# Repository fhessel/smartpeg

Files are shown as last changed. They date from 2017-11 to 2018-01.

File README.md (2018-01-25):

# smartpeg
Project "Smarte Wäscheklammer" for Ambient Intelligence at TU Darmstadt, winter term 2017/18

## About the project
This repository contains hardware definitions and software to build a prototype of a _smart peg_ that you can attach to your
drying laundry. It will estimate the remaining time until the laundry is completely dry and notifcy you on your Android phone.

The project consists of the following components:

- The hardware, an actual peg, an ESP8266 microcontroller board, humidity and temperature sensors and a battery. Descriptions on
how to build the hardware are available in the `hardware/schematics` folder.
- The microcontroller software, written in C/C++, can be found at `hardware/code`, more details on how to build it are provided
by the README file in the `hardware` folder.
- The server component, written as Java Web Application (we used Tomcat for testing), can be found in the `api` directory,
together with the database and API description files
- The machine learning scripts are written in Python 3 and use TensorFlow, they are located in the `server` directory
- The Android app, written in Java, is located in the `app` folder.

## What it looks like

The final hardware prototype looked like that. The PCB as well as the battery have roughly the length of the peg, so they can be glued together easily:

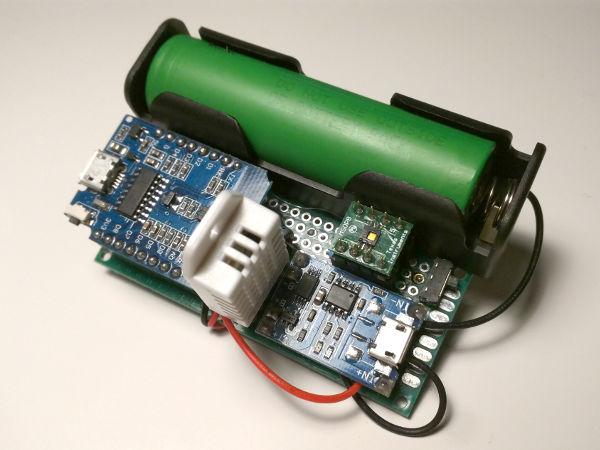
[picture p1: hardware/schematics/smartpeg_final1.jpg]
Front view of the final hardware prototype

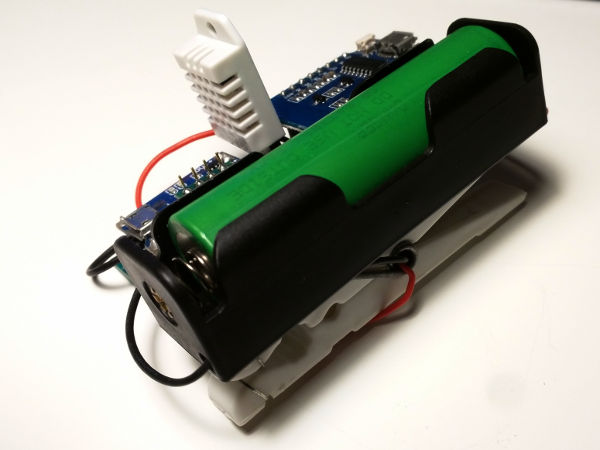
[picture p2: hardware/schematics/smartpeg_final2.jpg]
Rear view of the final hardware prototype


The following image shows a screenshot of one drying process together with the prediction of the neural network:

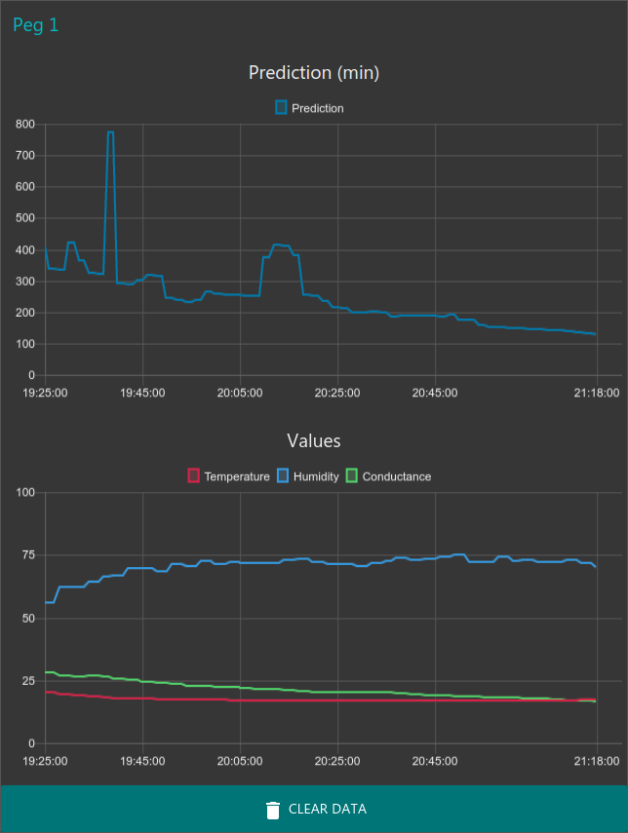
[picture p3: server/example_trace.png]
Prediction and measurement values


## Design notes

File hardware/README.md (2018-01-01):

# Hardware

This folder contains a description of the hardware (schematics) as well as the source code
for the ESP8266.

## Schematics

The subfolder contains the circuit design and schematics. The files can be edited with
[Fritzing](http://fritzing.org/home/).

### Parts list

The project currently makes use of:

- An ESP8266 development board, compatible to NodeMCU
  - XSource ESP8266 D1 mini ([Amazon Link](https://www.amazon.de/gp/product/B01ELFAF1S/))
  - Note: It has a slightly different pin layout as the more common Wemos D1 mini!
- A DHT22 temperature and humidity sensor
  - DHT11 should also work, if configured in the code
- A TI HDC1080 temperature and humidity sensor
  - Soldered on a 2x4 pin 0.1" breakout board for better handling
- A 20 mA blue LED
- Some resistors:
  - One 68 ohm resistor (for the LED)
  - One 1 mega ohm resistor (for measuring conductance of the clothes)
  - Two 4.7 kilo ohm resistors (pull-up for communication lines of I²C)
- A 470µF capacitor
- A switch
- A 1N4007 diode
- A peg that has wires on both of the clamp
- An 18650 LiPo battery (capacity should be irrelevant, but the one used had 2500mAh)
  - Charging controller including TP4056 (charging) and DW01x (discharge protection)
  - Holder for the battery

The 1N4007 diode is used to introduce a fixed voltage drop, because the 4.2V present while micro USB for
charging is connected would harm the ESP8266.

### Resources

- [Guide on calculating I²C pullup resistors](http://www.ti.com/lit/an/slva689/slva689.pdf) by Texas Instrucments
- [Data Sheet for HDC1080](http://www.ti.com/lit/ds/symlink/hdc1080.pdf) temperature and humidity sensor
- [Data Sheet for DHT22](https://www.sparkfun.com/datasheets/Sensors/Temperature/DHT22.pdf) temperature and humidity sensor

### Circuit Design

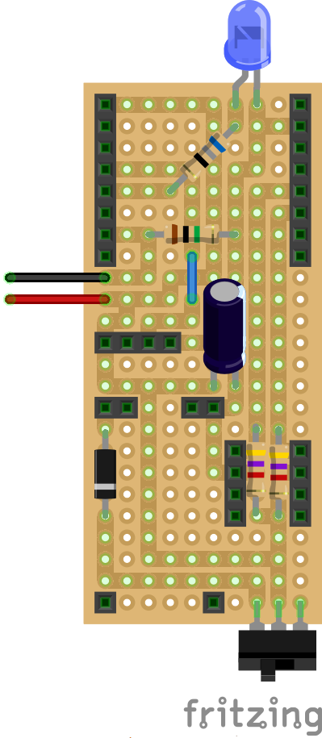
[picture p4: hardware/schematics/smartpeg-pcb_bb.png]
Circuit on PCB


The PCB layout uses female headers for most components, including sensors, the ESP8266 board and a PCB that contains the components
for control of charging and discharging. It has the dimensions of 10 by 24 and uses the common 0.1 inch distance between holes.

Both of the top-most size 8 headers are used to connect the ESP8266 board, with the micro USB port facing to the upper side of the image.
This means, the (unused) 5V pin is on the top-right corner.

The single size 4 header on the left is used to connect the DHT22, with the Vcc pin at the border of the PCB.

On the bottom right, there are two size four headers to connect the HDC1080, and on the bottom left, the charging controller is placed on the
remaining headers.

The following photo shows the assembled PCB, the battery and the peg:

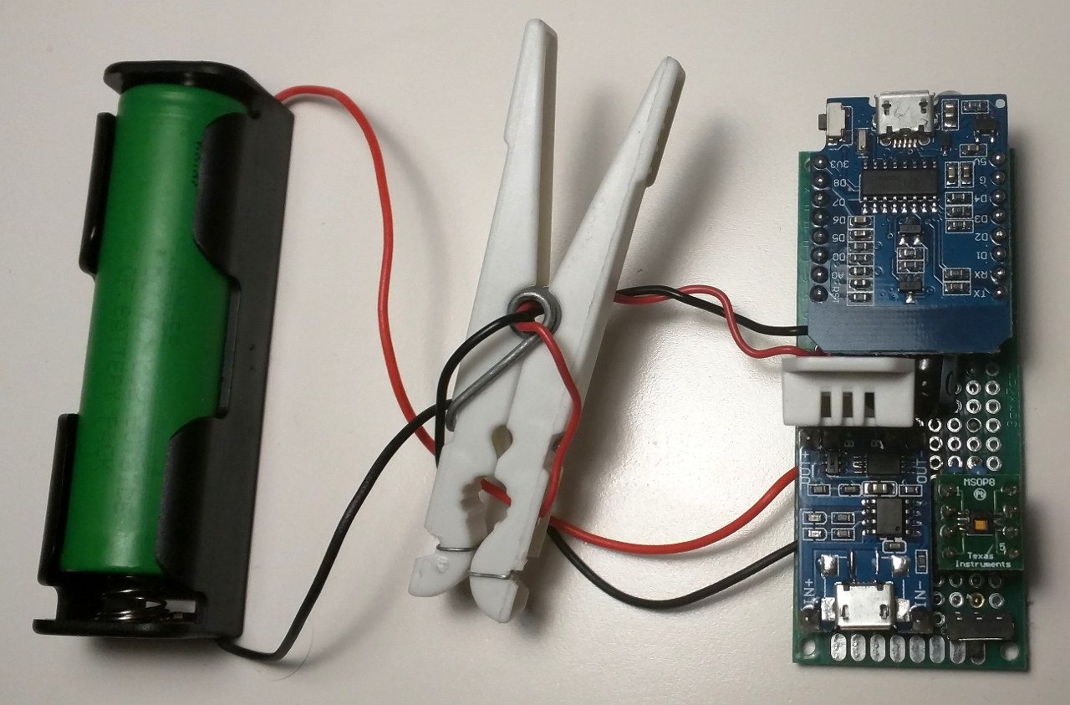
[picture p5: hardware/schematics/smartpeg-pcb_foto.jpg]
Photo of PCB


**Note:** Only one sensor is required for the circuit, if you decide to assemble it with only one sensor, the other one can be disabled in the code.

## Code

The code subfolder contains the project that generates the program running on the ESP8266
microcontroller.

### Setup

While the ESP8266 is Arduino-compatible, for bigger projects a full IDE is easier to use.
For that reason, the project is developed using the Eclipse-based [Sloeber IDE](http://eclipse.baeyens.it/).

The code folder is an Eclipse project folder that can be imported into a normal workspace.

To setup the development environment:

- Download [Sloeber](http://eclipse.baeyens.it/)
- Get the [ESP8266 Arduino Core](https://github.com/esp8266/Arduino) and follow the instructions to install it.
- Checkout the project into a new workspace
- Copy all foo.example.h files in the /config folder to get an individual configuration (instructions included in the files)
- Compile the project and upload it to the board

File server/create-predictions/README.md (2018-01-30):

# createPredictions.jar

Some lines of Java code to re-generate historical predictions. Needs mariadb connector and Apache commons-lang3 as jar in the classpath and should be exported as createPredictions.jar. Remember configuring the values in the DatabaseConnector class.

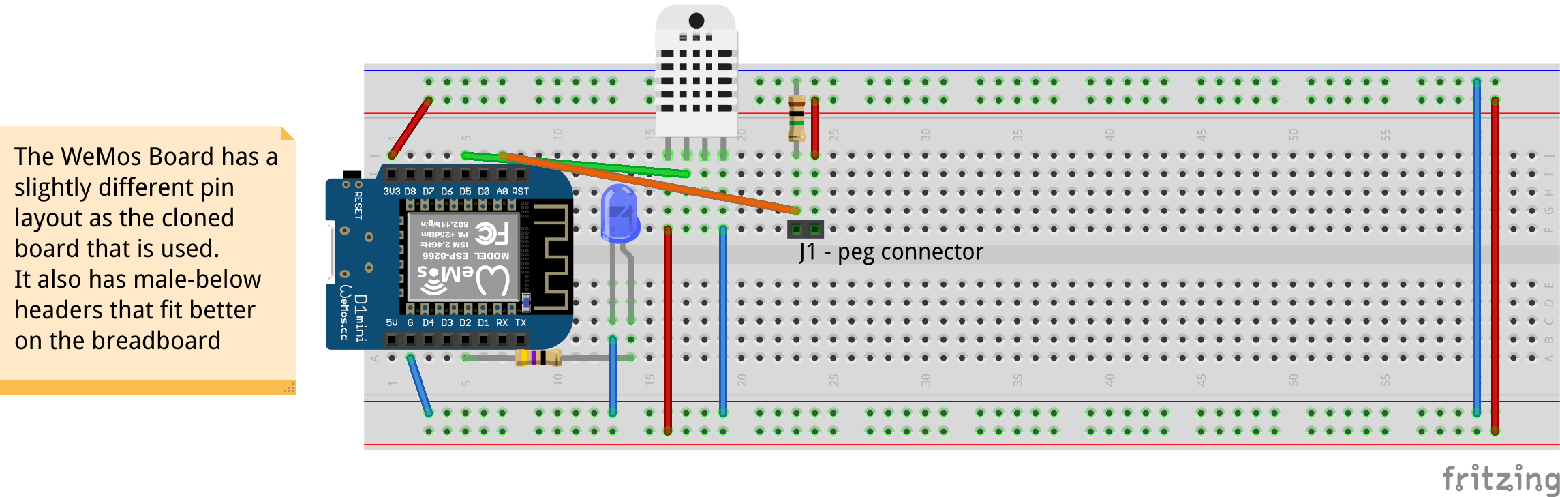
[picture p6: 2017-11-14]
hardware/schematics/smartpeg_bb.png

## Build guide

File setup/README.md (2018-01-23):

# Setup instructions

This guide will help you setting up the project including the server. For development purposes, we used a Raspberry Pi (Version 3) as server. Other distributions or even OSs should work, but the further you get away from Debian-like systems, the more things will have to be adapted.

## Setting up the server

The server is a Java web application, so it needs a Java server that is at least capable of running the Web Profile. In our case, Tomcat 8 was quite useful. It also requires a JDK:

```
apt-get install tomcat8 openjdk-8-jdk
```

Besides that, we need a database to store measurements, known pegs etc. We used MySQL and MariaDB for this:

```
apt-get install mariadb-server mariadb-client
```

The server needs to have the **right JDBC-Connector in the classpath**, so for example download [mariadb-java-client-2.2.0.jar](https://downloads.mariadb.org/connector-java/2.2.0/) and put it into `/var/lib/tomcat8/lib/`.

Create a `smartpeg` database user with a secure password and his own database `smartpeg`. The setup script for the database as `api/databaseDef.sql` in the repository.

The newly-created database then has to be configured in the server. To do so, edit `/var/lib/tomcat8/conf/context.xml` and add the following lines:

```
<Resource name="jdbc/smartpeg" auth="Container"
	type="javax.sql.DataSource"
	description="Connection to MariaDB"
	username="smartpeg"
	password="the-secure-password-you-created-before"
	driverClassName="org.mariadb.jdbc.Driver"
	url="jdbc:mariadb://localhost:3306/smartpeg"
/>
```

For the python scripts (machine learning), we need to point the server to a script location. This may be anywhere in the system (however, the server needs write access), but to use it in combination with the auto deployment feature (see below), we put it in a path on the `smartpeg` user's home directory.

This location also needs to be configured in the `context.xml`:

```
<Environment name="pythonServerBase" value="/home/smartpeg/data/smartpeg-python" type="java.lang.String"/>
```

**Note:** For the development server started within the IDE, a sample local configuration file is provided within the workspace and included in the maven build file.

**Note:** This is a very simple configuration, where the SmartPeg app will be the only app deployed in the servers root. In a multi-app setup, it's __highly__ recommended to make the above configuration entries in an app-only visible context file.

After configuring everything, restart the server: `systemctl restart tomcat8`

## Python-Scripts

The `server` folder of the repository contains python scripts for machine learning and some previously trained models. They need to be located at a place where the `tomcat8` (managing the virtual environment) user may write, as well as the `smartpeg` user (auto deployment feature, see below).

We use a directory in the home-directory of the `smartpeg` user:

```
mkdir /home/smartpeg/data
mkdir /home/smartpeg/data/smartpeg-python
chown smartpeg:tomcat8 /home/smartpeg/data/smartpeg-python
chmod u=rw,g=rws,o=r /home/smartpeg/data/smartpeg-python
```

To populate the folder, either run auto deployment or copy the content of the `server` directory of the repository into `smartpeg-python`.

Eventhough a virtual environment is created, some prequisites have to be available on the system to do so:

```
apt-get install python3 python3-virtualenv python-virtualenv libblas-dev liblaspack-dev libatlas-dev libatlas-base-dev
```

**Note:** The Java application will call a shell script (`predict.sh`). When setting up the application on Windows, this has to be changed in the Java code.

**Note:** The Python virtual environment is created on-the-fly when the first prediction should be made by the `predict.sh` shell script.

## Autodeployment

Auto deployment is a tool that updates Java and Python application everytime the `deploy-master` branch of the remote repository changes.

More details on it can be found in the autodeployment subfolder.

## Manual deployment

To deploy the application manually, run the following commands to build it (working directory: `api/rest` in the repository):

```
mvn clean
mvn install
```

Then, copy rename the created `.war`-file from the `target` directory to `ROOT.war` and drop it into `/var/lib/tomcat8/smartpeg/`

The server will update the application within some seconds.

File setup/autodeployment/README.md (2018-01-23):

# Autodeployment

This folder contains all scripts that are required to deploy changes in the repository automatically to the server.

The script ...
- Pulls from git
- Compares the hashcodes of the previous and the new latest commit, and stops if nothing has changed
- When a change has been detected, the script
  - Performs a maven clean on the Java source code directory
  - Performs a maven build on the Java source code directory
  - Deletes the local python folder
  - Copys everything from the server directory of the repository to the local python folder
  - Deploys the latest build of the Java web application to the local tomcat8 server
- Finally, depending of the outcome of the deployment process, a success or failure notice is sent to all recipients listed in `mail.addresses.notify`

**Note:** It might be a good idea NOT to run this script directly from the local copy of the repository as it might override itself during auto deployment with undefined behavior. Furthermore, the script creates temporary files in this directory that are not included from version control, which may lead to failing pulls.

**Note:** The script is configured to keep up to the **branch** `deploy-api`, so that not every change to the master automatically gets pulled by the server.

## Setup of the script

Checkout the project's repository at `~/repositories/smartpeg` in the home of your `smartpeg` user.

Copy the whole `autodeployment` folder to `~/cron/autodeploy-smartpeg-api` in the home directory of your `smartpeg` user.

Check all template-files etc. for optional adjustment (e.g. you want to change the mail address in the notification templates)

If not yet done, `apt-get install tomcat8 openjdk-8-jdk maven sendmail git` and configure sendmail properly.

Make sure, the `smartpeg` user is allowed to write to `/var/lib/tomcat8/smartpeg/` and that it is member of the group `tomcat8` to delete temporary files created while running the scripts.

To activate the script, create a cron job to call the `cron.sh` script regularly, for example, if you wish a check for updates every 10 minutes, you can use the following line:

```
#  m   h  dom   mon   dow   command
*/10   *    *     *     *   /home/smartpeg/cron/autodeploy-smartpeg-api/cron.sh > /dev/null
```

The `smartpeg` user needs to be able to (at least) read the git repository to do the pull. In practice, GitHub's _deployment keys_ feature might become handy here.

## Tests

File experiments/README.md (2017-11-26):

# Experiments

This folder contains data captured during experiments with the hardware, machine learning etc.

## Hardware traces

2017-11-11-experiment01.csv is the first trace under real conditions and has a duration of 8h, it was captured indoor on a rainy day,
with an open window. At the end of the trace, most of the clothes have been dry, the sweatshirt with the sensor attached
to it did not completely dry within the 8 hours (that's why the sensor readings do not reach 0 in the end).

2017-11-14-experiment02.csv - real conditions, indoor, not rainy, window open. The first 3 hours are not included in the trace,
in the end, the clothes have been mostly dry. Some gaps in the data are caused by the tcp wifi transmission protocol, which is
not that stable.

2017-11-20-experiment03.csv - real conditions, indoor, rainy, window open. Starts in the moment the clothes started to dry.

2017-11-25-experiment04.csv - real conditions, indoor, rainy day, from beginning. Includes readings for both sensors.

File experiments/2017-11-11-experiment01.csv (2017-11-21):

sensor | time_ms | humidity_percent | temperature_degc | dryness_raw
DHT22 | 2369853 | 51.099998 | 22.299999 | 51.710655
DHT22 | 2370629 | 51.099998 | 22.299999 | 45.259041
DHT22 | 2371130 | 51.099998 | 22.299999 | 43.206257
DHT22 | 2371631 | 51.099998 | 22.299999 | 41.935482
DHT22 | 2372132 | 50.900002 | 22.299999 | 56.989246
DHT22 | 2372908 | 50.900002 | 22.299999 | 57.575756
DHT22 | 2373409 | 50.900002 | 22.299999 | 50.439884
DHT22 | 2373910 | 50.900002 | 22.299999 | 47.311829
DHT22 | 2374411 | 50.799999 | 22.299999 | 40.762463
DHT22 | 2375187 | 50.799999 | 22.299999 | 53.372433
DHT22 | 2375688 | 50.799999 | 22.299999 | 57.575756
DHT22 | 2376189 | 50.799999 | 22.299999 | 55.816227
DHT22 | 2376690 | 50.599998 | 22.200001 | 39.687195
DHT22 | 2377466 | 50.599998 | 22.200001 | 40.273705
DHT22 | 2377967 | 50.599998 | 22.200001 | 40.566959
DHT22 | 2378468 | 50.599998 | 22.200001 | 41.055717
DHT22 | 2378969 | 50.500000 | 22.299999 | 36.265884
DHT22 | 2379745 | 50.500000 | 22.299999 | 39.980450
DHT22 | 2380246 | 50.500000 | 22.299999 | 39.589443
DHT22 | 2380747 | 50.500000 | 22.299999 | 40.175953
DHT22 | 2381248 | 50.500000 | 22.400000 | 22.482893
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

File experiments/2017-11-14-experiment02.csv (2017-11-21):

sensor | time_ms | humidity_percent | temperature_degc | dryness_raw
DHT22 | 71338 | 56.799999 | 21.799999 | 23.264908
DHT22 | 72113 | 56.799999 | 21.799999 | 22.971651
DHT22 | 72614 | 56.799999 | 21.799999 | 2.443793
DHT22 | 73115 | 56.799999 | 21.799999 | 0.000000
DHT22 | 73616 | 56.799999 | 21.799999 | 23.460411
DHT22 | 74391 | 56.799999 | 21.799999 | 22.971651
DHT22 | 74892 | 56.799999 | 21.799999 | 2.346041
DHT22 | 75393 | 56.799999 | 21.799999 | 0.000000
DHT22 | 75894 | 56.799999 | 21.799999 | 23.460411
DHT22 | 76669 | 56.799999 | 21.799999 | 23.264908
DHT22 | 77170 | 56.799999 | 21.799999 | 1.857283
DHT22 | 77671 | 56.799999 | 21.799999 | 0.000000
DHT22 | 78172 | 56.799999 | 21.799999 | 23.264908
DHT22 | 78947 | 56.799999 | 21.799999 | 22.873899
DHT22 | 79448 | 56.799999 | 21.799999 | 1.857283
DHT22 | 79949 | 56.799999 | 21.799999 | 0.000000
DHT22 | 80450 | 56.799999 | 21.799999 | 23.655914
DHT22 | 81225 | 56.799999 | 21.799999 | 22.971651
DHT22 | 81726 | 56.799999 | 21.799999 | 1.173020
DHT22 | 82227 | 56.799999 | 21.799999 | 0.000000
DHT22 | 82728 | 57.000000 | 22.000000 | 23.264908
DHT22 | 83503 | 57.000000 | 22.000000 | 22.776148
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

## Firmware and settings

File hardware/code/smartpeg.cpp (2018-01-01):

// Do not remove the include below
#include "smartpeg.h"

#ifdef USE_HDC1080
// Temperature and humidity sensor HDC1080, connected to D2 (=SDA) and D1 (=SCL) via I²C
HDC1080 sensor = HDC1080(SDA, SCL);
#endif

#ifdef USE_DHT22
DHT dht = DHT(PIN_DHT22, DHT22);
#endif

// Peg sensor (checks for conductivity of the peg)
Peg peg    = Peg(PIN_PEG);

String url = "http://smartpeg.fhessel.de/smartpeg/peg/" + String(PEG_ID) + "/readings";

//The setup function is called once at startup of the sketch
void setup()
{
	// Setup status LED
	pinMode(PIN_LED_WIFI, OUTPUT);

	setupSerialMonitor();

	// Signal initiation of setup
	for (int i = 0; i < 3; i++) {
		delay(500);
		digitalWrite(PIN_LED_WIFI, HIGH);
		delay(500);
		digitalWrite(PIN_LED_WIFI, LOW);
	}

// Configure sensors depending on the configuration in config/measurement.h
#ifdef USE_DHT22
	setupDHTSensor();
#endif
#ifdef USE_HDC1080
	setupHDCSensor();
#endif
#ifndef USE_HDC1080
#ifndef USE_DHT22
	Serial.println("ERROR: NO SENSOR CONFIGURED. PLEASE ACTIVATE EITHER \"USE_DHT22\" OR");
	Serial.println("       \"USE_HDC1080\" IN config/measurement.h!");
#endif
#endif
	setupWiFi();

	Serial.println(String("Trasmitting values to ") + url);

	// Signal finish of setup
	for (int i = 0; i < 3; i++) {
		delay(800);
		digitalWrite(PIN_LED_WIFI, HIGH);
		delay(200);
		digitalWrite(PIN_LED_WIFI, LOW);
	}
}

// The loop function is called in an endless loop
void loop()
{
	// Show the sensor is alive
	digitalWrite(PIN_LED_WIFI, HIGH);
	delay(50);
	digitalWrite(PIN_LED_WIFI, LOW);
	delay(50);

	float dryness     = peg.readDryness();

#ifdef USE_HDC1080
	float temperature = sensor.getTemperature();
	float humidity    = sensor.getHumidity();

	// Start transmitting only after the sensors are ready
	if (temperature + humidity > 0.001f) {
		// humidity, temperature, dryness
		storeMeasurement(temperature, humidity, dryness, SENSOR_TYPE_HDC1080);
	} else {
		Serial.println("HDC Sensor is not ready, not recording any values");
	}
#endif

#ifdef USE_DHT22
	float temperatureDht = dht.readTemperature();
	float humidityDht    = dht.readHumidity();

	storeMeasurement(temperatureDht, humidityDht, dryness, SENSOR_TYPE_DHT22);
#endif

#ifdef USE_HDC1080
	// Trigger next measurement (the sensor needs some time);
	sensor.triggerMeasurement();
#endif

	// The following code is the strategy to keep WiFi off for most of the time to save energy.
	// We store all measurements in an array and only transmit them if the array is nearly full
	// (nearly full to avoid dismissing values if the transmission fails)

	// Check remaining storage space (in periods, that's why we devide by PER_STEP).
	int storageSpaceLeft = (MEASUREMENT_STORAGE_SIZE - storedMeasurementsPointer) / MEASUREMENTS_PER_STEP;

	Serial.print("Measurements have been taken. ");
	Serial.print(storedMeasurementsPointer);Serial.print(" of ");Serial.print(MEASUREMENT_STORAGE_SIZE);
	Serial.print(" are used. ");Serial.print(storageSpaceLeft);Serial.println(" periods until buffer is full");

	// If less than TRANSMIT_PERCENTAGE% space is left, prepare value transmission
	if (storedMeasurementsPointer >= (MEASUREMENT_STORAGE_SIZE*TRANSMIT_PERCENTAGE)/100) {
		// This value is required to calculate the time that has been used for communication
		unsigned long wifiTime = millis();

		// At first, try to establish a wifi connection
		if (WiFi.status() != WL_CONNECTED) {
			WiFi.forceSleepWake();
			wifiConnectLoop();

			// If the connection could not be established
			if (WiFi.status() != WL_CONNECTED) {
				// Randomly use disconnect() sometimes, as the esp8266 somehow "needs" this
				if (random(100) < 33) {
					WiFi.disconnect();
				}
			}
		} else if (WiFi.status() == WL_CONNECTED) {
			// If WiFi has been connected, transmit values
			// We use else if above because connecting takes some seconds and this would mean
			// transmission is interrupted short after it has started.
			transmitMeasurements();
			if (storedMeasurementsPointer == 0) {
				// This means success, so we cann disable wifi again.
				WiFi.disconnect();
				WiFi.forceSleepBegin();
			}
		}

		// check how much time we used for communcation etc.
		wifiTime = millis()-wifiTime;
		if (wifiTime < MEASUREMENT_PERIOD) {
			// If communication took less than measurement_period, then sleep
			// for the remaining time
			delay(MEASUREMENT_PERIOD - wifiTime);
		}
	} else {
		// Sleep just until the next measurement
		delay(MEASUREMENT_PERIOD);
	}

}

void transmitMeasurements() {
	unsigned long ms = millis();



	// We need to batch the data transmissions as HTTPClient does not like IP segmentation.
	// With an MTU of ~1400 byte payload, using 8 entries per request leaves roughly 175 byte
	// per entry, which should suffice. One could make this dynamic by checking the string length
	// but this seens to be a fairly good approach.
	const int valuesPerTransmission = 8;
	while(transmittedMeasurementsPointer < storedMeasurementsPointer) {
		int lastIdx = (transmittedMeasurementsPointer+valuesPerTransmission < storedMeasurementsPointer ?
				transmittedMeasurementsPointer+valuesPerTransmission :
				storedMeasurementsPointer);

		HTTPClient httpClient;
		httpClient.begin(url);
		httpClient.addHeader("Content-Type", "application/json");

		// Start the json array
		String jsonPayload = "[";
		for(int i = transmittedMeasurementsPointer; i < lastIdx; i++) {
			// For all but the first entry, add a comma to the json string
			if (i > transmittedMeasurementsPointer) {
				jsonPayload+=",";
			}

			// Create the JSON for a single entry
			measurement_t * measurement = (&storedMeasurements[i]);

			String sensorType = "unknown";
#ifdef USE_DHT22
			if (measurement->sensor_type == SENSOR_TYPE_DHT22) sensorType="DHT22";
#endif
#ifdef USE_HDC1080
			if (measurement->sensor_type == SENSOR_TYPE_HDC1080) sensorType="HDC1080";
#endif
			jsonPayload +=
				String("{\"humidity\":") +
				String(measurement->humidity, 5) +
				String(",\"temperature\":") +
				String(measurement->temperature, 5) +
				String(",\"conductance\":") +
				String(measurement->dryness, 5) +
				String(",\"sensor_type\":\"") +
				sensorType +
				String("\",\"timeOffset\":-") +
				String( (ms-(measurement->time_ms))/1000 ) +
				String("}");

			// If this was the last entry, terminate the json array
			if (i == lastIdx -1) {
				jsonPayload+="]";
			}
		}

		// Send the request
		int httpStatusCode = httpClient.POST(jsonPayload);

		if (httpStatusCode >= 200 && httpStatusCode < 300) {
			// Successful, use the next batch
			transmittedMeasurementsPointer = lastIdx;
			Serial.print("Partial Transmission successful.");
		} else {
			// An error occured
			Serial.print("HTTP POST failed. Got return code: ");
			Serial.print(httpStatusCode, DEC);

			// Show the error using the LED
			for(int i = 1; i < 10; i++) {
				digitalWrite(PIN_LED_WIFI, HIGH);
				delay(50);
				digitalWrite(PIN_LED_WIFI, LOW);
				delay(50);
			}

			if (httpStatusCode >= 400 && httpStatusCode < 500) {
				Serial.print("\n -> Skipping this batch (4xx = Client error, retry will not help)\n");
				Serial.print(" -> JSON was:\n    ");
				Serial.print(jsonPayload);
				Serial.print("\n   ");
				transmittedMeasurementsPointer = lastIdx;
			}
		}
		Serial.print(" (");
		Serial.print(transmittedMeasurementsPointer);
		Serial.print(" of ");
		Serial.print(storedMeasurementsPointer);
		Serial.println(" transmitted)");
		httpClient.end();


		if (
				// Interrupt if the measurement_period has been exceeded badly.
				(millis() - ms > MEASUREMENT_PERIOD * 2) &&
				// Only if transmission isn't complete
				(storedMeasurementsPointer > transmittedMeasurementsPointer) &&
				// Only if there's space left in the buffer (where should we store the measurement otherwise?!)
				(storedMeasurementsPointer < MEASUREMENT_STORAGE_SIZE - MEASUREMENTS_PER_STEP)
		) {
			Serial.println("Interrupting transmission to take a measurement");
			return;
		}
	}
	// Reset buffer pointers
	Serial.println("All values have been transmitted successfully");
	storedMeasurementsPointer = 0;
	transmittedMeasurementsPointer = 0;

}

void storeMeasurement(float temp, float hum, float dryness, int sensor_type) {
	// Validation (check NaN)
	if (temp != temp || hum != hum) {
		Serial.println("Ommitting measurement (some value was NaN)");
		return;
	}

	if (storedMeasurementsPointer < MEASUREMENT_STORAGE_SIZE) {
		measurement_t * measurement = (&storedMeasurements[storedMeasurementsPointer]);

		measurement->dryness     = dryness;
		measurement->humidity    = hum;
		measurement->temperature = temp;
		measurement->sensor_type = sensor_type;
		measurement->time_ms     = millis();

		storedMeasurementsPointer += 1;
	} else {
		Serial.println("Cannot store more measurements. Dropping current measurement!");
		for(int i = 1; i < 4; i++) {
			digitalWrite(PIN_LED_WIFI, HIGH);
			delay(150);
			digitalWrite(PIN_LED_WIFI, LOW);
			delay(50);
		}
	}
}

#ifdef USE_HDC1080
void setupHDCSensor() {
	// Initialize the library. Easy.
	Serial.print("Setting up HDC1080 sensor...");
	uint8_t err = sensor.begin();
	if (err) {
		Serial.print(" Failed");
		while(1) {
			delay(1000);
			Serial.print(".");
		}
	}
	Serial.println(" Done.");
	Serial.print("Triggering initial read...");
	sensor.triggerMeasurement();
	Serial.println(" Done.");
}
#endif

void setupWiFi() {
	Serial.print("Setting up WiFi...");

	// Turn of system clock between transmissions
	WiFi.mode(WIFI_STA);
	WiFi.setSleepMode(WIFI_LIGHT_SLEEP);
	WiFi.disconnect();
	WiFi.forceSleepBegin();

	// Print some status information
	Serial.println(" Done.");
}

void wifiConnectLoop() {
	Serial.println("Trying to connect to WiFi");
	digitalWrite(PIN_LED_WIFI, HIGH);

	WiFi.begin(WIFI_SSID, WIFI_PSK);
	for(int tries = 0; tries < MEASUREMENT_PERIOD/250 && WiFi.status() != WL_CONNECTED; tries++) {
		// This will make the led blink
		digitalWrite(PIN_LED_WIFI, (tries&1) ? HIGH : LOW);

		Serial.print(".");
		delay(250);
	}

	if (WiFi.status() == WL_CONNECTED) {
		Serial.println(" Connected!");
	} else {
		Serial.println(" No connection...");
	}

	// Set the LED low to show the connection has been established
	digitalWrite(PIN_LED_WIFI, LOW);
}

void setupSerialMonitor() {
	// Setup the serial port for debugging.
	// Include a delay to make the connection more stable
	// (without delay, some output might be missing)
	Serial.begin(115200);
	delay(2000);
}

#ifdef USE_DHT22
void setupDHTSensor() {
	Serial.print("Setting up DHT22 sensor...");
	dht.begin();
	Serial.println(" Done.");
}
#endif

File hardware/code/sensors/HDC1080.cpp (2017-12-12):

/*
 * HDC1080.cpp
 *
 *  Created on: Nov 21, 2017
 *      Author: frank
 */

#include "HDC1080.h"

#define HDC_DEVICE_ADDRESS        0b1000000 // see manual
#define HDC_CLOCK_FREQ            100000    // 100 kHz

// Measure temperature and humidity together
#define HDC_CONF_MEASURE_TEMPHUM  (0x01 << 12)

// Measure temperature with 14 bit precision
#define HDC_CONF_TEMPRES_14BIT    (0x00 << 10)
// Measure temperature with 11 bit precision
#define HDC_CONF_TEMPRES_11BIT    (0x01 << 10)

// Measure humidity with 14 bit precision
#define HDC_CONF_HUMRES_14BIT     (0x00 << 9)
// Measure humidity with 11 bit precision
#define HDC_CONF_HUMRES_11BIT     (0x01 << 9)
// Measure humidity with 8 bit precision
#define HDC_CONF_HUMRES_8BIT      (0x02 << 9)

// Activate heater during measurement
#define HDC_CONF_ACTIVATE_HEATER  (0x01 << 13)

// Address pointer value to trigger measurements
#define HDC_ADDR_TRIGGER_MEASURE  0x00

// Register to read temperature from
#define HDC_ADDR_TEMPERATURE      0x00
// Register to read humidity from
#define HDC_ADDR_HUMIDITY         0x01

// Address of the configuraton register
#define HDC_ADDR_CONFIGURATION    0x02

// Duration of a measurement in ms
#define HDC_MEASUREMENT_DURATION 1000

HDC1080::HDC1080(uint8_t sda, uint8_t scl):
	_sda(sda),
	_scl(scl) {
	_lastMeasurement = 0;
	_temperature = 0.0f;
	_humidity = 0.0f;
}

HDC1080::~HDC1080() {

}

uint8_t HDC1080::begin() {
	// Configure the I²C bus
	Wire.begin(_sda, _scl);
	Wire.setClock(HDC_CLOCK_FREQ); // 100kHz (HDC supports 10-400)

	// The sensor has a device startup time of 10-15ms
	// We wait for that (could be done better but will work for the beginning)
	while(millis() < 15) {
		delay(1);
	}

	// Configure the sensor by the configuration registers
	return setupConfigurationRegisters();
}

uint8_t HDC1080::setupConfigurationRegisters() {

	uint8_t  pointerRegister = HDC_ADDR_CONFIGURATION;
	uint16_t registerValue   =
			HDC_CONF_MEASURE_TEMPHUM |
			HDC_CONF_ACTIVATE_HEATER |
			HDC_CONF_TEMPRES_14BIT |
			HDC_CONF_HUMRES_14BIT;

	Wire.beginTransmission(HDC_DEVICE_ADDRESS);

		Wire.write(pointerRegister);
		Wire.write((uint8_t)(registerValue >> 8));
		Wire.write((uint8_t)(registerValue));

	uint8_t err = Wire.endTransmission();
	Serial.println(err, HEX);
	return err;
}

/**
 * Triggers a measurement on the sensor.
 *
 * This will require some time before the values can actually be called
 */
uint8_t HDC1080::triggerMeasurement() {
	unsigned long ms = millis();

	// Only start a new measurement if there is not one ongoing
	if (_lastMeasurement < (millis() - HDC_MEASUREMENT_DURATION)) {

		// Trigger measurement
		Wire.beginTransmission(HDC_DEVICE_ADDRESS);
			Wire.write(HDC_ADDR_TRIGGER_MEASURE);
		uint8_t err = Wire.endTransmission();

		if (!err) {
			// Set the time that this measurement has been triggered
			_lastMeasurement = ms;
		}

		return err;
	} else {
		// No transmission, no error, return 0
		return 0;
	}
}

/**
 * Gets the latest value for humidity.
 *
 * If a measurement has been triggered some time ago, this method might
 * first fetch the humidity
 */
float HDC1080::getHumidity() {
	// Check whether there is a newer measurement
	tryReadMeasurements();

	// return the newest measurement
	return _humidity;
}

/**
 * Gets the latest value for humidity.
 *
 * If a measurement has been triggered some time ago, this method might
 * first fetch the temperature
 */
float HDC1080::getTemperature() {
	// Check whether there is a newer measurement
	tryReadMeasurements();

	// return the newest measurement
	return _temperature;
}

/**
 * Reads a measurement register from the sensor
 */
uint8_t HDC1080::tryReadMeasurements() {
	if (_lastMeasurement > 0 && _lastMeasurement < millis() - HDC_MEASUREMENT_DURATION) {

		// Request values (4 Bytes: temp msb, temp lsb, hum msb, hum lsb)
		uint8_t bytesRead = Wire.requestFrom(HDC_DEVICE_ADDRESS, 4);

		// Only continue if we received an answer (and the sensor was ready)
		if (bytesRead == 4) {

			uint16_t temp_raw = (Wire.read() << 8) + Wire.read();
			uint16_t hum_raw  = (Wire.read() << 8) + Wire.read();

			// See data sheet page 14
			_temperature = (((float)temp_raw)*165.0f)/(65536.0f)-40.0f;
			_humidity = ((float)hum_raw)/(655.36f);

			// Mark this value as read
			_lastMeasurement = 0;
		}

	}

	// Nothing to read, no error
	return 0;
}

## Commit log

2017-11-11 Added first test trace from the hardware
    [2017-11-11-experiment01.csv]
2017-11-14 Added breadboard schematics. Resolves #2 - The breadboard hardware prototype is working
    [smartpeg.fzz]
2017-11-14 Created project structure, resolves #15
    [smartpeg.cpp]
2017-11-15 More experimental data
    [2017-11-14-experiment02.csv]
2017-11-21 Added experiment 03
    [2017-11-20-experiment03.csv]
2017-11-21 Added sensor type to experiment csv files
    [2017-11-11-experiment01.csv, 2017-11-14-experiment02.csv, 2017-11-20-experiment03.csv]
2017-11-22 Switched to HDC1080 sensor
2017-11-22 Added sensor name to CSV output
2017-11-24 Database lookup through JNDI
    [test-app-context.xml]
2017-11-24 Fixed humidity reading for the hdc1080
    [HDC1080.cpp]
2017-11-26 New experiment, with parallel evaluation of both sensors
    [2017-11-25-experiment04.csv]
2017-11-27 Added code to read both sensors to the hardware
2017-12-01 #3 - Added sensor_type to post request, changed data type of conductance to float
2017-12-01 Resolve #17 - The hardware now calls the api on the test server
    [smartpeg.cpp]
2017-12-09 Resolves #21, Sensor is now read correctly
    [HDC1080.cpp]
2017-12-09 Added config file for peg ID and connected sensors. Made the script ready to run on low-power mode (see #18 for mor details)
2017-12-20 Extended database definition for creating training samples
2018-01-01 Added some notes on the final hardware design
    [smartpeg-pcb.fzz]
2018-01-01 Added some fancy LED blinking during hardware setup
2018-01-01 Adjusted the conductance threshold after rebuilding the circuit
2018-01-20 Added config and scripts to call the tf python script from java
    [test-app-context.xml]
2018-01-20 Added requirements for the raspberry pi
